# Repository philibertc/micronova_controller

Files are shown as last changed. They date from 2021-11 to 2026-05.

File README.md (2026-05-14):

# micronova_controller  

<a href="https://www.tindie.com/products/philibertc/pellet-heater-controller/">
  I sell on Tindie
</a>
<a href="https://www.paypal.com/donate?hosted_button_id=337V43Y2JEU5L">
  Donate with PayPal
</a>

**Kits are available on Tindie!**  
**_In stock every month._**  

**Here is an overview of the additions:**

- **possibility to reset the settings with a flat screwdriver**
- **IO footprints are now designed to accept screw terminals**
- **D0 and RST are connected for deep sleep**
- **a row of pins has been added to access unused pins**

This Arduino program allows to control easily via MQTT a pellet stove equipped with a Micronova mainboard. Hardware details [here.](https://github.com/philibertc/micronova_controller_pcb/)  
**Discord server: https://github.com/philibertc/micronova_controller/discussions/63**

## License
<br />This work is licensed under a <a rel="license" href="http://creativecommons.org/licenses/by-nc-sa/4.0/">Creative Commons Attribution-NonCommercial-ShareAlike 4.0 International License</a>.
All previous commits [from this one (3 sept 2022)](https://github.com/philibertc/micronova_controller/commit/3b48e56f5a7b02a50885eb272f03c7dd73d8c4e8) are CC-BY-NC-ND and not CC-BY-NC-SA.

## Please check the [Wiki](https://github.com/philibertc/micronova_controller/wiki)

## Thanks
Thanks to [@pedrware](https://github.com/pedrware) for the photo of the mainboard and his explanations of some of the problems encountered.  
Thanks to [ridiculouslab](https://www.ridiculouslab.com/arguments/iot/stufa/micronova_en.php) for his analysis of the serial protocol.  
Thanks to the active Discord community, who keep the project moving.  
Thanks to [PCBWay](https://www.pcbway.com/) for supporting me in the production of PCBs.

## Disclaimer
THIS SOFTWARE IS PROVIDED "AS IS" AND ANY EXPRESSED OR IMPLIED WARRANTIES, INCLUDING, BUT NOT LIMITED TO, THE IMPLIED WARRANTIES OF MERCHANTABILITY AND FITNESS FOR A PARTICULAR PURPOSE ARE DISCLAIMED. IN NO EVENT SHALL THE REGENTS OR CONTRIBUTORS BE LIABLE FOR ANY DIRECT, INDIRECT, INCIDENTAL, SPECIAL, EXEMPLARY, OR CONSEQUENTIAL DAMAGES (INCLUDING, BUT NOT LIMITED TO, PROCUREMENT OF SUBSTITUTE GOODS OR SERVICES; LOSS OF USE, DATA, OR PROFITS; OR BUSINESS INTERRUPTION)
HOWEVER CAUSED AND ON ANY THEORY OF LIABILITY, WHETHER IN CONTRACT, STRICT LIABILITY, OR TORT (INCLUDING NEGLIGENCE OR OTHERWISE) ARISING IN ANY WAY OUT OF THE USE OF THIS SOFTWARE, EVEN IF ADVISED OF THE POSSIBILITY OF SUCH DAMAGE.

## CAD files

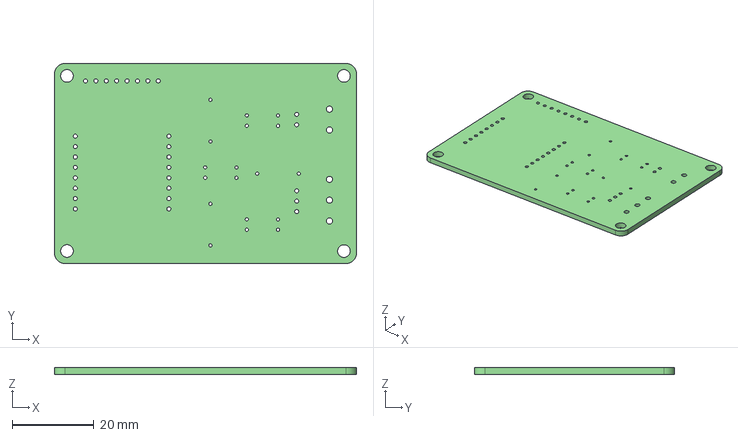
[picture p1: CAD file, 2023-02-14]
Useful things/PCB(v1.2).step
73.8 x 48.9 x 1.60 mm

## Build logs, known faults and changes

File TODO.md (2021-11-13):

### Things to implement in the firmware
- [X] Water pressure read
- [X] Fans speed control (will not be implemented if EEPROM, _not implemented_)
- [ ] Fans speed reading
- [ ] Flame power control (maybe it has to be set in EEPROM, maybe RAM 0x19)
- [ ] Eco off state reading
- [ ] Eco off state writing
- [ ] Eco off timer reading
- [ ] Eco off timer writing
- [ ] Thermostat reading
- [ ] Thermostat writing
- [ ] Ping distance sensor
- [ ] Intake air temp
- [X] Deep Sleep

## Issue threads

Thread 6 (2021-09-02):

Invalid flue gas temperature

philibertc, 2021-09-02:
### Discussed in https://github.com/philibertc/micronova_controller/discussions/5

philibertc, 2021-09-12:
Solved on commit "Fume temp" https://github.com/philibertc/micronova_controller/commit/77ca5469e7868de4700d771c248f1fcc638f5586

philibertc, 2021-10-16:
The problem has been solved for several people, but for some the value is not stored on the same memory address. So I will work on referencing all possible addresses.

philibertc, 2021-11-05:
## List of possible addresses
- 0x3E (default)
- 0x5A

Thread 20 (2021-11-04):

Flue gas temp (was on 0x5A for Micronova Mod0047 EVO) and waterpres incorrect

geraldFS, 2021-11-04:
Hello everyone, today was the day. I used the controls in Homeassistant.

Basically it works - but:
- The smoke temperature does not fit a maximum of 10 ° C
- The water pressure is stated three times too high
- Flame power remains at 0 (but you can only see it in the MQTT Explorer

Pellet stove used:
ITC Layma 18kW
Micronova Mod0047 EVO

Addendum to the interference suppression, as soon as I use the 18V from the motherboard, my WLAN quality drops, now I use an interference suppression board (filtering / smoothing the input voltage), the WLAN reception is good.

philibertc, 2021-11-05:
Hello,
To analyze which addresses might match, you can use this program: [test2bis](https://github.com/philibertc/micronova_controller/blob/master/tests/esp8266/test2bis_read_all_addresses.ino)
Which buck converter do you use? I personally have sufficient smoothing with an LM2596.

geraldFS, 2021-11-05:
Hi there,

these are my standard DC / DC converters, they work wonderfully.
But as I said after I repeatedly had problems with other devices, that they received interference from outside, I got used to always smoothing the voltage with capacitors. Since then, all problems have been resolved.

How do I use the test2bis?

I compiled it and uploaded it but then ...

https://de.aliexpress.com/item/4000259403990.html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

geraldFS, 2021-11-05:
fumesTempAddr = 0x5A

philibertc, 2021-11-05:
> https://de.aliexpress.com/item/4000259403990.html

Ah, okay, these are "mini" models. I'm used to these: https://m.media-amazon.com/images/I/61VvzQgykgL._AC_SY355_.jpg which have a more consistent smoothing.

> I compiled it and uploaded it but then ...

Ah, yes, sorry. You have to open the serial monitor (115200 bauds) to analyze the results and eventually find one corresponding to the value you are looking for.

> fumesTempAddr = 0x5A

It works for you with that value?

geraldFS, 2021-11-05:
```
12:55:41.866 ->
12:55:41.866 -> --------------- CUT HERE FOR EXCEPTION DECODER ---------------
12:55:41.900 ->
12:55:41.900 -> Exception (0):
12:55:41.900 -> epc1=0x43420e04 epc2=0x00000000 epc3=0x00000000 excvaddr=0x00000000 depc=0x00000000
12:55:41.900 ->
12:55:41.900 -> >>>stack>>>
12:55:41.900 ->
12:55:41.900 -> ctx: cont
12:55:41.900 -> sp: 3ffffdc0 end: 3fffffc0 offset: 0190
12:55:41.900 -> 3fffff50:  3ffee080 3ffee650 00000046 3ffee5ec
12:55:41.900 -> 3fffff60:  3fffda00 3ffee650 00000046 402025a4
12:55:41.900 -> 3fffff70:  40202c65 00000046 3ffee5ec 402010e2
12:55:41.900 -> 3fffff80:  3fffdad0 00000000 000000cf 40201160
12:55:41.933 -> 3fffff90:  00000100 00000000 feefeffe feefeffe
12:55:41.933 -> 3fffffa0:  feefeffe feefeffe 3ffee5d8 402026c0
12:55:41.933 -> 3fffffb0:  feefeffe feefeffe 3ffe85d8 401011e1
12:55:41.933 -> <<<stack<<<
12:55:41.933 ->
12:55:41.933 -> --------------- CUT HERE FOR EXCEPTION DECODER ---------------
12:55:41.967 ->
12:55:41.967 ->  ets Jan  8 2013,rst cause:2, boot mode:(3,6)
12:55:41.967 ->
12:55:41.967 -> load 0x4010f000, len 3460, room 16
12:55:41.967 -> tail 4
12:55:41.967 -> chksum 0xcc
12:55:41.967 -> load 0x3fff20b8, len 40, room 4
12:55:41.967 -> tail 4
12:55:41.967 -> chksum 0xc9
12:55:41.967 -> csum 0xc9
12:55:41.967 -> v00043510
12:55:41.967 -> ~ld
12:55:44.111 -> Param=0 value=a90  169
12:56:14.975 ->
12:56:14.975 -> --------------- CUT HERE FOR EXCEPTION DECODER ---------------
12:56:14.975 ->
12:56:14.975 -> Exception (9):
12:56:14.975 -> epc1=0x43420e04 epc2=0x00000000 epc3=0x00000000 excvaddr=0x00000011 depc=0x00000000
12:56:15.008 ->
12:56:15.008 -> >>>stack>>>
12:56:15.008 ->
12:56:15.008 -> ctx: cont
12:56:15.008 -> sp: 3ffffdc0 end: 3fffffc0 offset: 0190
12:56:15.008 -> 3fffff50:  3ffee080 3ffee650 00000046 3ffee5ec
12:56:15.008 -> 3fffff60:  3fffda00 3ffee650 00000046 402025a4
12:56:15.008 -> 3fffff70:  40202c65 00000046 3ffee5ec 402010e2
12:56:15.008 -> 3fffff80:  3fffdad0 00000000 000000cf 40201160
12:56:15.008 -> 3fffff90:  00000100 00000000 feefeffe feefeffe
12:56:15.042 -> 3fffffa0:  feefeffe feefeffe 3ffee5d8 402026c0
12:56:15.042 -> 3fffffb0:  feefeffe feefeffe 3ffe85d8 401011e1
12:56:15.042 -> <<<stack<<<
12:56:15.042 ->
12:56:15.042 -> --------------- CUT HERE FOR EXCEPTION DECODER ---------------
12:56:15.042 ->
12:56:15.042 ->  ets Jan  8 2013,rst cause:2, boot mode:(3,6)
12:56:15.042 ->
12:56:15.042 -> load 0x4010f000, len 3460, room 16
12:56:15.075 -> tail 4
12:56:15.075 -> chksum 0xcc
12:56:15.075 -> load 0x3fff20b8, len 40, room 4
12:56:15.075 -> tail 4
12:56:15.075 -> chksum 0xc9
12:56:15.075 -> csum 0xc9
12:56:15.075 -> v00043510
12:56:15.075 -> ~ld
12:56:17.208 -> Param=0 value=c40  196
12:56:36.567 ->
12:56:36.567 -> --------------- CUT HERE FOR EXCEPTION DECODER ---------------
12:56:36.567 ->
12:56:36.567 -> Exception (9):
12:56:36.567 -> epc1=0x40204f26 epc2=0x00000000 epc3=0x00000000 excvaddr=0x40205236 depc=0x00000000
12:56:36.676 ->
12:56:36.676 -> >>>stack>>>
12:56:36.676 ->
12:56:36.676 -> ctx: cont
12:56:36.676 -> sp: 3ffffdc0 end: 3fffffc0 offset: 0190
12:56:36.676 -> 3fffff50:  3ffee080 3ffee650 00000046 3ffee5ec
12:56:36.676 -> 3fffff60:  3fffda00 3ffee650 00000046 402025a4
12:56:36.676 -> 3fffff70:  40202c65 00000046 3ffee5ec 402010e2
12:56:36.676 -> 3fffff80:  3fffdad0 00000000 00000082 40201160
12:56:36.676 -> 3fffff90:  00000100 00000000 feefeffe feefeffe
12:56:36.676 -> 3fffffa0:  feefeffe feefeffe 3ffee5d8 402026c0
12:56:36.676 -> 3fffffb0:  feefeffe feefeffe 3ffe85d8 401011e1
12:56:36.676 -> <<<stack<<<
12:56:36.676 ->
12:56:36.676 -> --------------- CUT HERE FOR EXCEPTION DECODER ---------------
12:56:36.676 ->
12:56:36.676 ->  ets Jan  8 2013,rst cause:2, boot mode:(3,6)
12:56:36.676 ->
12:56:36.676 -> load 0x4010f000, len 3460, room 16
12:56:36.676 -> tail 4
12:56:36.676 -> chksum 0xcc
12:56:36.676 -> load 0x3fff20b8, len 40, room 4
12:56:36.676 -> tail 4
12:56:36.676 -> chksum 0xc9
12:56:36.676 -> csum 0xc9
12:56:36.676 -> v00043510
12:56:36.676 -> ~ld
12:56:38.814 -> Param=0 value=180  24
12:57:08.924 ->
12:57:08.924 -> --------------- CUT HERE FOR EXCEPTION DECODER ---------------
12:57:09.015 ->
12:57:09.015 -> Exception (3):
12:57:09.015 -> epc1=0x43420e06 epc2=0x00000000 epc3=0x00000000 excvaddr=0x40204f30 depc=0x00000000
12:57:09.015 ->
12:57:09.015 -> >>>stack>>>
12:57:09.015 ->
12:57:09.015 -> ctx: cont
12:57:09.015 -> sp: 3ffffdc0 end: 3fffffc0 offset: 0190
12:57:09.015 -> 3fffff50:  3ffee080 3ffee650 00000046 3ffee5ec
12:57:09.015 -> 3fffff60:  3fffda00 3ffee650 00000046 402025a4
12:57:09.015 -> 3fffff70:  40202c65 00000046 3ffee5ec 402010e2
12:57:09.015 -> 3fffff80:  3fffdad0 00000000 000000ca 40201160
12:57:09.015 -> 3fffff90:  00000100 00000000 feefeffe feefeffe
12:57:09.015 -> 3fffffa0:  feefeffe feefeffe 3ffee5d8 402026c0
12:57:09.015 -> 3fffffb0:  feefeffe feefeffe 3ffe85d8 401011e1
12:57:09.015 -> <<<stack<<<
12:57:09.015 ->
12:57:09.015 -> --------------- CUT HERE FOR EXCEPTION DECODER ---------------
12:57:09.015 ->
12:57:09.015 ->  ets Jan  8 2013,rst cause:2, boot mode:(3,6)
12:57:09.015 ->
12:57:09.015 -> load 0x4010f000, len 3460, room 16
12:57:09.015 -> tail 4
12:57:09.015 -> chksum 0xcc
12:57:09.015 -> load 0x3fff20b8, len 40, room 4
12:57:09.015 -> tail 4
12:57:09.015 -> chksum 0xc9
12:57:09.015 -> csum 0xc9
12:57:09.015 -> v00043510
12:57:09.015 -> ~ld
12:57:11.163 -> Param=0 value=160  22
12:57:41.301 ->
12:57:41.301 -> --------------- CUT HERE FOR EXCEPTION DECODER ---------------
12:57:41.301 ->
12:57:41.301 -> Exception (0):
12:57:41.301 -> epc1=0x43420e04 epc2=0x00000000 epc3=0x00000000 excvaddr=0x40204f30 depc=0x00000000
12:57:41.301 ->
12:57:41.301 -> >>>stack>>>
12:57:41.301 ->
12:57:41.301 -> ctx: cont
12:57:41.301 -> sp: 3ffffdc0 end: 3fffffc0 offset: 0190
12:57:41.301 -> 3fffff50:  3ffee080 3ffee650 00000046 3ffee5ec
12:57:41.301 -> 3fffff60:  3fffda00 3ffee650 00000046 402025a4
12:57:41.382 -> 3fffff70:  40202c65 00000046 3ffee5ec 402010e2
12:57:41.382 -> 3fffff80:  3fffdad0 00000000 000000ca 40201160
12:57:41.382 -> 3fffff90:  00000100 00000000 feefeffe feefeffe
12:57:41.382 -> 3fffffa0:  feefeffe feefeffe 3ffee5d8 402026c0
12:57:41.382 -> 3fffffb0:  feefeffe feefeffe 3ffe85d8 401011e1
12:57:41.382 -> <<<stack<<<
12:57:41.382 ->
12:57:41.382 -> --------------- CUT HERE FOR EXCEPTION DECODER ---------------
12:57:41.382 ->
12:57:41.382 ->  ets Jan  8 2013,rst cause:2, boot mode:(3,6)
12:57:41.382 ->
12:57:41.382 -> load 0x4010f000, len 3460, room 16
12:57:41.382 -> tail 4
12:57:41.382 -> chksum 0xcc
12:57:41.382 -> load 0x3fff20b8, len 40, room 4
12:57:41.382 -> tail 4
12:57:41.382 -> chksum 0xc9
12:57:41.382 -> csum 0xc9
12:57:41.382 -> v00043510
12:57:41.382 -> ~ld
12:57:43.537 -> Param=0 value=140  20
12:58:02.891 ->
12:58:02.891 -> --------------- CUT HERE FOR EXCEPTION DECODER ---------------
12:58:02.891 ->
12:58:02.891 -> Exception (9):
12:58:02.891 -> epc1=0x40204f26 epc2=0x00000000 epc3=0x00000000 excvaddr=0x40205236 depc=0x00000000
12:58:02.891 ->
12:58:02.891 -> >>>stack>>>
12:58:02.891 ->
12:58:02.891 -> ctx: cont
12:58:02.891 -> sp: 3ffffdc0 end: 3fffffc0 offset: 0190
12:58:02.891 -> 3fffff50:  3ffee080 3ffee650 00000046 3ffee5ec
12:58:02.891 -> 3fffff60:  3fffda00 3ffee650 00000046 402025a4
12:58:02.973 -> 3fffff70:  40202c65 00000046 3ffee5ec 402010e2
12:58:02.973 -> 3fffff80:  3fffdad0 00000000 00000082 40201160
12:58:02.973 -> 3fffff90:  00000100 00000000 feefeffe feefeffe
12:58:02.973 -> 3fffffa0:  feefeffe feefeffe 3ffee5d8 402026c0
12:58:02.973 -> 3fffffb0:  feefeffe feefeffe 3ffe85d8 401011e1
12:58:02.973 -> <<<stack<<<
12:58:02.973 ->
12:58:02.973 -> --------------- CUT HERE FOR EXCEPTION DECODER ---------------
12:58:02.973 ->
12:58:02.973 ->  ets Jan  8 2013,rst cause:2, boot mode:(3,6)
12:58:02.973 ->
12:58:02.973 -> load 0x4010f000, len 3460, room 16
12:58:02.973 -> tail 4
12:58:02.973 -> chksum 0xcc
12:58:02.973 -> load 0x3fff20b8, len 40, room 4
12:58:02.973 -> tail 4
12:58:02.973 -> chksum 0xc9
12:58:02.973 -> csum 0xc9
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
geraldFS, 2021-11-05:
fumesTempAddr = 0x5A

It works for you with that value?

Yes!

philibertc, 2021-11-05:
Cool! One problem solved quickly
For the water pressure, if it is constantly 3× higher you can edit the [line 369](https://github.com/philibertc/micronova_controller/blob/ee899ee48db1be8ea5414a327f024a538e55d4d3/micronova_controller.ino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) by adding ` / 3`.

geraldFS, 2021-11-05:
I've already thought about this, but that shouldn't be the solution.

I am afraid I am using the wrong value or my oven is not delivering it.
I have to deactivate the water pressure measurement during the initial setup as soon as the pipeline set is installed.
Therefore I fear that the value in the form no longer exists.

Italian technology that inspires ;-))

But I can live very well without the water pressure, there are other things that press me more.

philibertc, 2021-11-05:
> I've already thought about this, but that shouldn't be the solution.

Yes, but only until then. There's still the flame power reading to fix, right?

geraldFS, 2021-11-05:
With the new .ino of today, errors are gone, now the heating power requirement goes.

the value that is displayed for water pressure also corresponds to what has been transferred, think either the oven delivers a fake value.

I just drained the water because I installed a small return increase and the value stayed exactly the same ...

geraldFS, 2021-11-15:
Hi there,

I can confirm that the ITC Layma (18Kw) works with the Micronova Mod 0047 EVO.

There are two changes to the standard version:
- fumesTempAddr = 0x5A
- water pressure is not used by the control; it must always be deactivated. (see manual)

But otherwise TOP!

philibertc, 2021-11-15:
Hello,
thanks for the contribution!

Closed 2021-11-05.

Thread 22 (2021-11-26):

Problems with power OFF / power demand

geraldFS, 2021-11-26:
Hi there,

QA strikes again ;-)

Since the penultimate change to the source code, I have had the symptoms that I cannot switch off the oven if it has been running for a long time.
I can shift gears, but it continues to burn stubbornly.

The water temperature and room temperature are updated and are valid.
Only the switch on / off and the power requirement are frozen.

When I switch off the oven on the display, everything is updated and works again.

Regards
Gerald

philibertc, 2021-11-26:
Hello, I will roll back to the previous commit, that new changes were
untested but I forgot to switch on dev branch.

Le ven. 26 nov. 2021 à 12:05, Gerald ***@***.***> a écrit :

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

philibertc, 2021-11-26:
I revert the changes

geraldFS, 2021-11-26:
Thanks!
Reacts again :-)

geraldFS, 2021-12-07:
Hi there,

with the version dated December 4th, 2021 - the same phenomenon occurs again!

Switching on is possible
Switching off is not possible

Values are all displayed accordingly.

philibertc, 2021-12-07:
Hello, that's strange...
I will inspect this soon.

philibertc, 2021-12-07:
Hello, I reread the code, but I do not see anything that could influence the extinction. I will have to do some investigation.

philibertc, 2021-12-12:
Hello, until I have more information about this problem, I will roll back to the previous functional version.

philibertc, 2022-02-27:
Hello,
I'm going to make some simplifications in the program this weekend (especially in the web settings that I'm going to minimize to the wifi configuration until I know how to manage the rest better). This should make it easier to diagnose bugs like this one!

Best Regards,
Philibert

philibertc, 2022-09-11:
Hello,
Can I close this issue?

Sincerely,
Philibert

geraldFS, 2022-09-20:
Yes!

Closed 2022-09-20.

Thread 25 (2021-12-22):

make it works with ESPHOME

raziel83257, 2021-12-22:
It would be wonderfull to make it works with ESPHOME, that is also integrated with HomeAssistant:
https://esphome.io/index.html

philibertc, 2021-12-22:
Hello, I was thinking something more like this: https://github.com/philibertc/micronova_controller/discussions/15
For now I will make some other small improvements.
One day I'll probably make an esphome version.

Sincerely,
philibertc

geraldFS, 2022-09-20:
Perfect!
ESPhome would be the gold edge solution ;-)

Gerald

vyruz1986, 2022-11-10:
[This project](https://github.com/edenhaus/esphome-extraflame) offers a ESPHome component, pretty should it should work with the hardware of this project, as both software solutions (the arduino file in this repo, and the ESPHome config of the other repo) configure RX/TX pins which go to the stove's data pin

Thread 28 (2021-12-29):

Parameter based on model/type?

liquidacid, 2021-12-29:
Hi,

Currently im using your tool to fill my Home Assistant. It seems there is not really a good database of addresses available. I have an Artel Hydro stove and would like to share my address list based on the board in it. Maybe it would be awesome to build up a database of addresses?

Im about to adding more stuff which is interesting like fan speed, settings like amount of added pallets per time slot etc so you can combined with water temperature see if your stove needs to be cleaned over time etc.

philibertc, 2021-12-29:
Hello
>It seems there is not really a good database of addresses available

Yes, I'm building it with time, I'll soon create a document summarizing various things about the protocol used and the addresses.

>Im about to adding more stuff which is interesting like fan speed, settings like amount of added pallets per time slot

Unfortunately these parameters have to be written to the EEPROM, which is a memory that wears out rather quickly (about 10000 writes) and I haven't yet found a safe way to limit the number of writes in case of a bug.

Sincerely, philibertc

liquidacid, 2021-12-29:
I do understand, i don't want to write the values but only read them to make sure what the current settings are. They only should be sent once to the MQTT topic once they are changed in the stove i think so you can perfectly see the details.

I also got a very different set of addresses.

I suggest to make some different species in a seperate file where you can choose from to select the right stove?

philibertc, 2021-12-29:
> but only read them

Okay, in this case it's easy, I just didn't take the time to test the EEPROM reading, but it won't take me long to set up.

> I suggest to make some different species in a seperate file where you can choose from to select the right stove?

Yeah, that's a good idea, I will do that quickly.

liquidacid, 2021-12-29:
Im not asking you to do this, i can help if you like but if i only make it for myself its probably not the cleanest way of coding it.

philibertc, 2022-01-02:
Hello
Don't worry, I have to do it. If you want to make tests you can try to modify the program: https://github.com/philibertc/micronova_controller/blob/master/tests/esp8266/test2_read.ino
Sincerely, philibertc

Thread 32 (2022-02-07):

problem with micronova card of the year 2010

riccmike, 2022-02-07:
Thanks for your work, I tried to apply it to my Pellets Ecoteck stove with micronova board of the year 2010. With your code I didn't have any messages in the Serial Monitor, so I modified the code to understand what happens. I found that in my case, in the checkStoveReply function the rxCount variable is always zero. How has this ever happened to you? Perhaps the firmware of my board does not support communication, even if the serial connector is present.
I thank you in advance.

philibertc, 2022-02-12:
Hello, if there is the connector it is almost sure that it can communicate, because it can be useful in some cases for the repairer in case of failure.
This may be due to a bad connection. You can try this program to see if the stove reacts: https://github.com/philibertc/micronova_controller/blob/master/tests/esp8266/test1_on_off.ino
This program simply turns the stove on and off two seconds later.

Sorry for my late reply,
Sincerely,
philibertc

philibertc, 2022-02-16:
Hello,
This is really embarrassing.
Are you sure you have connected the cables correctly?
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
Sincerely,
philibertc

riccmike, 2022-02-16:
next weekend, I take the stove out of its position and retest the connector. Let's hope for my mistake. I will keep you updated.

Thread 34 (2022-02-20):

Add compatibility for ESP-01 and Breakout board

wes1993, 2022-02-20:
Hello,
could you help me to add compatibility for this board?
https://it.aliexpress.com/item/1005001970616935.html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

The breakout board can convert from 5V to 3.3V and also adapt the signal but need TX and RX pin, in this board we have only one serial PIN so i don't know how can i adapt this...

Best Regards
Stefano

philibertc, 2022-02-21:
Hello,

It will not be possible to adapt this breakout board because it is not advanced enough, it would need a few more GPIOs.
However, it should be possible to adapt the program for the ESP-01, still using the circuit with the optocouplers, but sacrificing some features like the serial port, which is very useful if everything does not work as expected.

Best Regards,
Philibert

wes1993, 2022-02-21:
Thanks a lor Philibert for your fast reply :-D
So i think i will keep the ESP8266 i just need to know what are the optocouplers to buy, do you have some link?
And did you know name/model of the female connector of the serial port on the micronova side?

Thanks a lot
Stefano

philibertc, 2022-02-21:
The optocouplers are PC817, 3 are needed
The esp8266 that fits best is the wemos d1 mini, which you can find by searching "d1 mini" on AliExpress or Amazon.
For the cable, this should be adequate: https://it.aliexpress.com/item/1005003638697583.html with 4 pins, 50cm mini and a female connector on one side.

Best Regards,
Philibert

wes1993, 2022-02-21:
Thanks again for your fast reply!!! :-D
I have found one Wemos D1 mini :-D so perfect i have the esp8266 i kust need the PC817... I have found two type of PC817 could you help me plese?:
This:
https://it.aliexpress.com/item/32719957788.html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

or this:

https://www.ebay.it/itm/173890434826?itemid=173890434826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

Best Regards
Stefano

philibertc, 2022-02-21:
The second one will be perfect!

wes1993, 2022-02-21:
Perfect thanks a lot!! :)
I’ll keep you updated and If I have some time I want to port this project on Blynk so we have an App and also HA integration

wes1993, 2022-02-22:
Hello Again @philibertc,
I have created the circuit and everything works fine!!!
I have only one question, there is a way to power on the ESP via 5V on the motherboard?

Best Regards
Stefano

philibertc, 2022-02-22:
Hello,
Glad everything is working!
I don't know if the stove is able to provide enough power via the 5V line, so I recommend using the 20V line with a converter like an LM2596 to get that down to 3.3V.

Best Regards,
Philibert

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

philibertc, 2022-02-22:
By the way, what is the model of your stove? So I can add it to the list of known models.

wes1993, 2022-02-22:
My stove is an El.Fire Venice Slim :)
But I should connect the GND together with the GND of ESP so did you think i could do that?

+ 20 V —> Converter —> Vin5V
GND    —> Converter —> GND of ESP

is the scheme correct?

wes1993, 2022-02-22:
P.S. I’m also trying to implement OTA updates, I will keep you update :)

Best Regard
Stefano

philibertc, 2022-02-22:
20 V —> Converter —> Vin5V *or 3V3 depending on the converter setting* but it is basically the same thing
GND —> Converter —> GND of ESP *= GND → Converter and GND → GND of ESP*

> My stove is an El.Fire Venice Slim :)

Thanks!
> I’m also trying to implement OTA updates, I will keep you update :)

That would be great, thank you very much!

wes1993, 2022-02-22:
Perfect thanks a lot :)

wes1993, 2022-02-22:
Hey another question.. sorry for the disturb :(
Did you know if there is a way to set the temperature and the clock?

philibertc, 2022-02-23:
Hello,
We are currently discussing it here: https://github.com/philibertc/micronova_controller/discussions/30 but for the moment the most reliable solution is to emulate the IR remote control.

Best Regards,
Philibert

wes1993, 2022-02-23:
ok perfect thanks a lot

wes1993, 2022-02-27:
Hello Philibert,
I have a question, I really really don’t understand why we need the 500 ohm resistor… could you help me?

Because I want, i case something won’t work, to attach the Micronova board to an arduino to convert TTL
To usb, but I think arduino is 5 v so I need to know if I just need to power the optocoupler via arduino and I have 5V or I also need to remove the resistor.

thanks a lot
Stefano

philibertc, 2022-02-27:
Hello,
an optocoupler works like this:
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
When we turn on the LED (on the left) the phototransistor on the other side becomes conductive. The 500 Ohms resistor (470 on the diagram) just allows not to burn out the led.

Electronically speaking, replacing the ESP by the Arduino works: the 500 Ohm resistor is also sufficient for 5V and not only 3V3. However, the Micronova board uses a strange serial configuration which is not available in the SoftwareSerial library for Arduino:
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
I will send you the procedure to use the Arduino as a serial converter, without using any program on it (just connecting to the RX and TX pins) and using a software like [YAT](https://sourceforge.net/projects/y-a-terminal/).

Best Regards,
Philibert

PS: I closed the issue but we can still discuss here.

wes1993, 2022-02-27:
@philibertc thanks a lot for your reply!! :) I will wait your instructions!! :)

philibertc, 2022-02-27:
I forgot a detail, in fact I realize that it is not possible to use to Arduino, even using it as a FTDI for example. The only solution is to use a program for the esp, which would play the role of a kind of bridge between the computer and the micronova board. I'm looking into how to do that.

wes1993, 2022-02-27:
Ok perfect thanks a lot!’ I will wait!’ :)

wes1993, 2022-02-28:
This is a WP of the mobile App:

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

what do you think? Do you like this?

bernardstef, 2022-02-28:
Hi !
I've been following this project and using it for a while ! Awesome to see a mobile app, I have the micronova wifi module (easy connect plus) + play store app and it's not the most reliable ..

wes1993, 2022-02-28:
I’m working on this, for now seems very powerful I just need to know how can we write value to eeprom in a safe way, I need the help of @philibertc for this and we could have the exact same function of the stock App.
This could be used for example for set the timer

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

best regards
Stefano

wes1993, 2022-03-01:
Hello,
I have some news :-D I have seen that someone has added the OTA code i will share my Blynk code also and i have added also the DUMP memory via a simple terminal command without connecting the device to PC.

@philibertc could you tell me if the values of params are decimals or HEX values?

Because for now i need to write the value in decimal otherwise the terminal can't accept the value.

Best regards
Stefano

wes1993, 2022-03-01:
Added also some Graph
![Uploading AD0D90D0-D85B-4F34-A5B0-ED079E0FAE80.png…]()

philibertc, 2023-02-10:
Hello,
I'm reopening this issue as I seem to have missed a lot of the discussion, sorry for that.
Has there been any progress?

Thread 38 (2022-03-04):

Why a 500 Ohm resistor

netdata-be, 2022-03-04:
Hi there,

I'm developing my own PCB because and I'm using your project as a base, thanks for that !

I'm just wondering why you picked a 500 ohm resistor, let me try to explain:

- 5V / 510 Ohm =  0,0098 A  == 9,8 mA
- 3,3V / 510 Ohm =  0,00064 == 6,4 mA

Since an optocoupler is just a LED it is designed to have 20mA over the IR LED

This means the ideal resistor should be:

- 5V / 0,02 A = 250 Ohm
- 3,3 V / 0,02 A =  165 Ohm

I'm guessing the led emits enough IR to activate the collector and thus work.
Or I'm I missing something?

philibertc, 2022-03-04:
Hello,

You are right, 250 Ohms resistors would be enough for that, but using about 500 allows to have a margin, because of the variable quality on sites like AliExpress but also to draw as little as possible on the 5V supplied by the stove.

Best Regards,
Philibert

PS: I'm closing this issue but you can still comment
https://github.com/philibertc/micronova_controller/issues/34#issuecomment-1053326781

Closed 2022-03-04.

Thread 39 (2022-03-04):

Why the use of the enable RX

netdata-be, 2022-03-04:
I'm wondering why you choose to use a GPIO to enable the RX from the 1wire RS232?
I would be interested to know the reason behind this.

philibertc, 2022-03-04:
Hello,
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
If you don't use the "enable RX" the RX optocoupler (in the middle) will act as a pullup as soon as you try to use the TX (at the bottom) : when the TX pin is set to GND, the current can pass from the other side (from pin 4 to 3) to GND and in the process allow the current to pass through the optocoupler in the middle, which will act as a pullup. The Stove_Serial pin therefore never makes the low signal.
This is one of the problems of half-duplex serial (on a single cable).
I hope my explanation is clear,

Best Regards,
Philibert

Closed 2022-03-06.

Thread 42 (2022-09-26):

Extraflame luisella stove not working/responding, other 4-pin pinout?

jeanpolle, 2022-09-26:
Hi everyone!

I have a luisella (extraflame) stove with 4-pin connector on on the back, but i can't get it working with the esp...
Before i take the stove off the pipe to have a look at the card internally; i thought i'd ask here; maybe i'm missing something obvious, i'm rather new to arduino ;)

i got the PCB from tindie, and have an ESP8266 wemos D1 mini fitted. Soldering all components went smooth. don't think i made an error there. (pics attached)

Programming the ESP doesn't work when it is fitted tot the PCB board however... it has trouble connecting, and the led starts blinkin erratically.
Once I remove it from the pcb, uploading the code works just fine. Can anyone comfirm the same behaviour?
i use the micro usb port to power the ESP.

Wifi setup works fine, I have a broker set up (mosquitto in a docker container) and can see the "pong" appear nicely every 25s.

I checked the serial port on the stove before connecting (good thing i did ;)), and when measuring the voltages i noticed a difference in pinout,  I found it to be: (gnd - 5v - 20v - ser) instead of  the documented (gnd - ser - 20v - 5v)

I hooked up the board, but nothing comes up other than the pong

-I tried the 2sec on/off program, but no reaction from the stove
-Test read.ino with a serial monitor running doens't show anything messages.

anything else you can think of? anyone found serial messages to be turned off in some admin menu-thing on the stove itself?

thanks!

J

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

philibertc, 2022-09-26:
Hello!
First of all, thank you for detailing your issue.
> don't think i made an error there.

Yes, it looks all good.
> Once I remove it from the pcb, uploading the code works just fine. Can anyone comfirm the same behaviour?

I have the same behavior, it's because of the link between D0 and RST which is used to add the possibility of deep sleep.
> i noticed a difference in pinout, I found it to be: (gnd - 5v - 20v - ser)

The serial and 5V pin are both at 5V, how did you tell the difference?

I hope I have answered a majority of your questions!
Do you have some resistors (above 1kOhm) and a multimeter at your disposal? There is a way to surely differentiate between serial and 5V.

Have a great day,
Philibert

jeanpolle, 2022-09-26:
Hi Philibert,

First of all, thanks for the excellent work done so far, great stuff! quite stunned :)

> The serial and 5V pin are both at 5V, how did you tell the difference?

Well..I wasn't sure what voltage to expect on the serial pin when measuring.
I have a pin which caries no voltage referenced to ground, and since I already had a 5v and 20v present; i figured it was the serial pin .. (was gonna ask how to be sure of this ;))

So that would explain why i get nothing; the 5v pin i measure will be the serial as per original pinout...
I do have resistors/multimeter at my disposal so if you got a trick to make sure, i'm all ears

Now what to do with the pin with no voltage... i measured it a few time, and to the ground pin i have 0v where you have 5v :)

i'll hook the pinout up as per spec/doc tonight or tomorow

Thanks for the help!

J

philibertc, 2022-09-26:
> I do have resistors/multimeter at my disposal so if you got a trick to make sure

Okay, nice!
To check which pin is serial, put your multimeter between GND and one of the two 5V pins. After, connect this pin to the GND via a resistor of more than 150 Ohm (not to make a short circuit or exceed the limit of 0.25W of a resistor), you can check if this pin is now at 0V. In this case, it is the serial pin, otherwise, it is the power supply pin.
Is this clear? I could make a diagram if you want.

From what you have described, the pinout described on the doc should actually be good, but it is always good to check.

Regards,
Philibert

jeanpolle, 2022-09-28:
Hi Philibert

little time, little knowledge, so progress is slow :)

I measured all pins again, and tried the resistor test to pull the serial to 0V.
It identified the documented 5V pin as the serial, good news!
The other pin (power) however remains at 0v instead of 5V all the time.

nevertheless, I corrected the wiring to the PCB and hooked it up to the stove but got no other messages from the ESP on the subscribed broker channels than "connected" on /pong.

nothing on /ambtemp, /state or /onoff

I connected another mqtt client to the broker and published messages on these topics, to check if my broker setup was working correctly. They showed up just fine on the first client.

I can however turn on the stove by publishing ON to /intopic, but the stove wont turn off when sending OFF.

I then loaded the on/off test.ino, and that worked. The stove went on and off again. Nice!
So why wont it turn OFF then when publishing OFF to /intopic.... weird.

it looks like a problem in this earlier thread...
https://github.com/philibertc/micronova_controller/issues/31

any ideas?

thanks!

J

philibertc, 2022-10-05:
Hello, first of all, sorry for my late reply
> So why wont it turn OFF then when publishing OFF to /intopic.... weird.

It is indeed strange. The fact that the ON/OFF test works already lets us know that it is not an address problem. When you send the message to turn off, does the blue LED of the WeMos blink (once and then several times right after)?

> it looks like a problem in this earlier thread...
https://github.com/philibertc/micronova_controller/issues/31

The problem does seem to be the same. I'll try to build a more advanced test program to find out what's wrong. The OFF command is normally built the same way as the ON, if one works I wonder what is blocking the other.

Bests,
Philibert

jeanpolle, 2022-10-06:
> Hello, first of all, sorry for my late reply

No problem, enough work to do here :)

> It is indeed strange. The fact that the ON/OFF test works already lets us know that it is not an address problem. When you send the message to turn off, does the blue LED of the WeMos blink (once and then several times right after)?

I remember the led blinking once when sending ON, and not blinking when sending OFF.
i'll try to confirm this later tonight.

> I'll try to build a more advanced test program to find out what's wrong. The OFF command is normally built the same way as the ON, if one works I wonder what is blocking the other.

the fact that no other parameters are published on any of the other topics (ambtemp / status / ...), would that solely be due to different addresses?

Thanks!

J

jeanpolle, 2022-10-25:
Hi guys,

got a bit of time on my hands; can anyone point me in a direction of things i can try?
Verify my method on how to run a serial monitor?
(running one in arduino IDE with the ESP connected via microUSB, and the serial connections to the stove, but i get absolutely nothing :))

J

philibertc, 2022-10-27:
> EDIT:
> The led blinks 1x short + 4x short when sending ON
> The led blinks 4x short when sending OFF

Hello!
All is good for the ON command, but it seems that the OFF command is not sent because the LED does not flash once in the first place.

Can you try reversing the ON and OFF command to see if the stove turns off (sending "on", since it will be reversed).

Bests,
Philibert

jeanpolle, 2022-10-27:
Hi Philibert,

Can you be more specific on how i should reverse the commands?

Would this mean altering the INO file and reuploading it to the ESP?
(as in; would reversing values in line 43 and 44 suffice? i'm a total noob at this)

Or am i missing an easier way?

kind regards!

J

philibertc, 2022-10-27:
that modification bypasses the two if conditions using ```if (true)```

jeanpolle, 2022-10-27:
Thanks so much; that works!

So the trouble lies in the controller reading the stove's status to be able to fullfill the condition, and only then send the command.

I don't get any data on other topics, so that problem is related....

What are the next steps to determine what goes wrong? other addresses, and how to find them?

Thanks for taking the time to help me out here; i'm learning a bunch of stuff ;)

Jan

msaitz, 2022-11-22:
I'm having the same issue with a Laminox Idro marichiara, I can only turn it ON with no additional actions or readings from the stove.
I'll be doing some additional testing to see if my issue fully matches @jeanpolle

jeanpolle, 2022-12-17:
did anyone make any progress?

@msaitz did you manage to get readouts?

msaitz, 2022-12-23:
@jeanpolle I haven't had time for it yet!

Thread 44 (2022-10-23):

MCZ Ego

ThomasTom86, 2022-10-23:
Good morning,
 I came across your amount when I was looking to make my pellet stove smart.  Unfortunately, my oven (MCZ Ego Air 2017) does not have a CN 13 port installed.  Is it still somehow possible to integrate this model into the iobroker via mqtt?  There is an original Wifi module for this oven (unfortunately very expensive).  Thanks

https://youtu.be/yPMMZ5ETMB8

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

jeanpolle, 2022-10-25:
If i had to guess; i'd say the 4 pins marked "com" are candidate for serial communication....

philibertc, 2022-10-27:
Hello,
According to the video, the "COM" pins seem to match. The use of only three cables also seems to confirm that it is the same protocol. You can make measurements with your multimeter by connecting the GND of the voltmeter to the 2nd from the left, then measuring the rest of the pins with the red probe.

Best Regards,
Philibert

ThomasTom86, 2022-10-27:
Thank you for your message.  This is the measurement result from the Com port.

Best regards
Tom
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

ThomasTom86, 2022-10-28:
I still found that
![Uploading E82E7FE0-994B-4061-98B0-E1E368BE3538.jpeg…]()

ThomasTom86, 2022-10-28:
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

Closed 2023-09-10.

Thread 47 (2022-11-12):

Wiring for La Nordica Extraflame Emma Plus

vyruz1986, 2022-11-12:
Hi,

First of all, thanks for putting this project together!

I'm trying to use this project to control/monitor the aforementioned pellet stove, but am struggling to find the right connections.
The control board I have is the one listed in [this PDF](https://www.extraflame.it/support/index.php?option=com_docman&Itemid=26&task=doc_download&gid=916) on page 40, 'board code' (whatever that may mean) 00227575.
Here's a picture of the board (sorry for poor quality, I took it from a webshop since mine is in the stove and I don't want to spend time disassembling it):
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

As you can see the 'Seriale' connector is positioned otherwise than in the readme of this repository.
In my stove, there is also a cable connected to it (tested all 3 wires, it's just an extension cable), which has a panel mount connector (exactly the same type as on the board) on the rear of the stove:
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

I also noticed that the extension cable only has 3 wires, while the board connector has 4 pins.
I measured all 4 pins with my DMM, and got the following results (numbering following your drawing of the connector in the readme):
1. GND, blue wire in extension cord (confirmed by measuring continuity between this pin and the negative CMOS battery pin
2. Black wire in extension cord, measuring constant +5V
3. Red wire in extension cord, measuring fluctuating +17-19V (approx every second)
4. No wire in extnesion cord, measuing constant +5V

I also measured all pins with my oscilloscope, but no obvious digital signal is visible.

So I'm at a loss as to which pin is the serial data pin, can someone help me out?

jeanpolle, 2022-11-16:
Hi!

looks like you are as confused as i was/am.... and are possibly running into the same problems. :)

have a look here;

https://github.com/philibertc/micronova_controller/issues/42#issue-1385697452

i found i can send stuff to the stove on the pinout philibert descibes (i assume yours will be the same) but cannot get a readout from the stove so we had to adapt the ino a bit to get the messages sent.

haven't scoped the output of my stove yet..

J

vyruz1986, 2022-11-16:
I forgot to mention I was (beside this and [this](https://github.com/netdata-be/PalletHeater-REST-API/issues/1) repository) also looking into [this](https://github.com/edenhaus/esphome-extraflame) solution, which I found the most attractive since it uses ESPHome allowing me to easily modify and upload new firmware in the future. With some help from @edenhaus I was able to get it working yesterday. The serial pin was indeed the 5V pin (pin #2) which was brought to the backpanel connector via the black wire.
I used this schematic to hook up my ESP8266:
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

It's different from the one described here , which I believe is better (since it uses optocouplers and offers complete isolation of ESP and stove), but as discussed above I couldn't get this schematic working :(
Also note that @edenhaus's solution doesn't require the `Enable_RX` pin which this solution needs.

edenhaus, 2022-11-17:
@vyruz1986 I have a logic shifter between the esp and the oven as the esp is not 5v tolerant.
I used a chinese copy of https://www.sparkfun.com/products/12009

vyruz1986, 2022-11-17:
> @vyruz1986 I have a logic shifter between the esp and the oven as the esp is not 5v tolerant. I used a chinese copy of https://www.sparkfun.com/products/12009

I know but I didn't have any logic shifter available, so I started with ESP8266 which is 5V tolerant (although not officially, I've used this MCU with 5V logic many times without problems. Also see [this](https://hackaday.com/2016/07/28/ask-hackaday-is-the-esp8266-5v-tolerant/)).
I have ordered logic shifters and will switch to ESP32 as soon as they arrive.

edenhaus, 2022-11-17:
Nice to know about the 5v tolerant. Maybe I will change on my load weight cell project to 5V to have a better precision. Thanks :)

@vyruz1986 It would be great to add the schematic above with the logic shifter to my repo. As you have already drawn it, feel free to add it with a PR :)

philibertc, 2022-11-17:
Hello,
> I also measured all pins with my oscilloscope, but no obvious digital signal is visible

This is normal: the stove does not send any information until it is asked.

> So I'm at a loss as to which pin is the serial data pin

According to this diagram it must be the second pin "Black wire in extension cord, measuring constant +5V" you measured:
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
the position of the "seriale" connector varies between the different models of micronova cards.

Best Regards,
philibertc

philibertc, 2022-11-17:
Have you tried any of the test programs?

bachtsevanis, 2023-02-20:
@vyruz1986 can you explaine how you connected with the board? I don't know how to read the diagram that you upload. My stove board has the same serial as yours. It's a Micronova J034_7

vyruz1986, 2023-02-21:
> @vyruz1986 can you explain how you connected with the board? I don't know how to read the diagram that you uploaded. My stove board has the same serial as yours. It's a Micronova J034_7

Read [this chapter](https://github.com/edenhaus/esphome-extraflame/blob/main/docs/connection.md#finding-the-right-pins) to find out how to identity the pins on your stove connector.
Once you found GND and DATA, connect GND to the ESP, and use a 1N4148 diode to wire the stove's DATA pin to the ESP's RX pin, with the black mark on the diode facing the ESP. Then branch another wire from the stove's DATA pin and connect it to the EPS's TX  pin.

bachtsevanis, 2023-02-22:
@vyruz1986 I suppose that you are not using external power ie USB power adapter like this solution?

rotragit, 2023-10-28:
Extraflame doen't wire the 5V pin on the backside socket. But you can get it from the socket on the controller. Use that one.

pippo93, 2024-11-10:
Any update about this issue? I have now finished the assembly of pcb as showed in this repo but I have the same Micronova Controller of the firat comment…

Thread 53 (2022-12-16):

Question about 5V Pin

eni23, 2022-12-16:
Hey @philibertc

I have a pellet stove (L'Asolana Marina) which clearly has a Micronova controller board, but i'm unable to access the PCB for interfacing with it. But it has a SUB9 connector on the back with has 3 connected pins (GND,20V,Serial).

 I would like your circuit, but the optocoupler that is connected to `RX_ENABLE` needs 5V which i do not have with the 3P-connection. Since its only driving a  optocoupler, i was thinking about using a step-down board and use the 20V to drive this optocoupler. Do you think this will work or is it too dangerous to try it? Any ideas?

I would use a circuit like this:
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

The official micronova WIFI board [pcb front](https://www.micronovasrl.com/wp-content/uploads/2016/02/DSC_2024.jpg) [pcb back](https://www.micronovasrl.com/wp-content/uploads/2016/02/DSC_2020.jpg) also only connects 3 pins and seem to directly convert the 20V down as well.

Thanks in advance :)

philibertc, 2022-12-26:
Hello!
Using a buck converter to do this is not a problem, you can definitely use this method.

Have a great day,
Philibert

eni23, 2022-12-27:
Thanks a lot for your answer. I tried it today and the stove replied and turned on as excepted. I will close here but will create a MR in the next few days to add my model to the supported ones in README.md.

Have a nice day as well :)

Closed 2022-12-27.

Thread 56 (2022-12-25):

Use the 5V from the new micro serial output.

maxcalavera81, 2022-12-25:
Hello @philibertc, what is the inconvenience of using the 5V output of the micro nova board to power your pcb and the wemos d1 mini?  So it would be possible to power everything without the need for external power.  I look forward to feedback, thank you very much for your attention...

philibertc, 2022-12-26:
Hello, the problem is that I don't know the maximum power available on this 5V line, while the ~20V line is the main low voltage supply of the stove, so I prefer to use this one through a buck converter.
So this is just a precaution.

Best Regards,
Philibert

Closed 2023-01-22.

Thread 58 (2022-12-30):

Safer way to turn the stove off

eni23, 2022-12-30:
Turning the stove on works fine over writing `0x01` to `RAM 0x21`, turning it off (sending `0x06` to `RAM 0x21`) seems to be problematic. My stove enters "turning off mode" but takes pretty long to do so (~50min), so this is not the procedure used by programs or the power button which takes around 10min. Searching around in the internet told me that i am not the only one which has this issue. The stove also has a infrared control, which seem to write commands to `RAM 0x58`. So sending 10 times `0x5a` to `RAM 0x58` with a delay of `100ms` turns the stove off safely.

You should consider changing your code to this method as well, since it seems the better way and also should work for all stoves.

There are other "IR commands" that can be written to `0x58` with a delay of `100ms`. To set power and temp, send it at least twice, for the power button (longpress) at least 10 times.

| State | Description   |
|-------|---------------|
| 0x54  | Power +       |
| 0x50  | Power -,      |
| 0x52  | Temperature + |
| 0x58  | Temperature - |
| 0x5a  | Power ON/OFF  |

philibertc, 2023-01-22:
Hello,
Thank you for your contribution!
I'm testing this out as soon as I can, then I'll probably incorporate it.
Bests,
philibertc

maxcalavera81, 2023-01-29:
I think I have the same problem. Because whenever I turn off the stove, I can turn it back on again. I don't really know what's going on.

paciotti, 2023-12-31:
Hello
I want to try this method for turning the stove ON and OFF since the original one is not working for my hydro stove.
How should we manage the checksum? If I'm not wrong the command should be {0x80, 0x58, 0x5a, 0x132} but the last value exceed the char dimension... Should we just use 0x32 instead?
Thank you for your clarification.

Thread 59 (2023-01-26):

Arduino ide deepSleepInstant error

maxcalavera81, 2023-01-26:
Hello, I'm having a "deepSleepInstant" error and I don't know how to solve it. Does anyone have any idea how or what I'm doing wrong?

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

philibertc, 2023-01-26:
Hello, it seems that you have selected the esp32 version of the D1 mini, this program is made especially for the esp8266 version

maxcalavera81, 2023-01-27:
@philibertc thank you very much, problem solved. It really was the poorly selected board. Thanks a lot for the project.

philibertc, 2023-01-27:
Hello, I am glad to hear that. Could you please tell me the model of your stove if everything works well? You can make a pull request for this, and be listed among the contributors.

maxcalavera81, 2023-01-27:
My stuva is a cadel crystal .  I'll do some more testing and then I'll give you feedback.

Closed 2023-01-27.

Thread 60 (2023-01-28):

States missing micro nova n100

maxcalavera81, 2023-01-28:
Hello @philibertc , I was here doing some tests and I noticed that there are missing states or possibly different states in your firmware. In the case I had a failure in the ignition and it continues to report loading pellets. Can you give me tips on how to solve this problem? My salamander is a crystal cadel with n100 board.

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

The machine shows a failure to ignition, alarm 5

Thank you very much for your attention

philibertc, 2023-02-10:
Hello,
everything is working properly finally ?

Bests,
philibertc

maxcalavera81, 2023-02-10:
Hello @philibertc Thank you for your concern.  Yes, it's already working.  The problem was really with wemos.  There are small updates here that maybe could improve the experience with the salamander via Wi-Fi (I don't know if it will be possible or even easy to implement 😜😜).  One of them would be the online and offline status in mqtt because even if it is not online it always shows the online status.  The other thing I noticed these days is that when an alarm occurs, it is not possible to turn it off remotely because the switch immediately goes off.  Again, I don't know if such a change will be possible.  Smoke temperature is not displayed with real values   (I don't know if it only happens to me).  And as for the warnings, I had a lack of pellets in the stove when in reality it was a misfire.  I don't know what the behavior is in this case, but the stove's LCD shows the right alert.  These are small adjustments that could be improved over time.  I can't stop thanking you for the fantastic work you've done.  It was just what I needed to control my heat.  PS: if you add a web interface for those who don't have a home assistant, I think it would be really great...

Closed 2023-01-29.

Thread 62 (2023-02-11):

How to make it work with Alexa

jayjay13011, 2023-02-11:
Hello philibert.
All works so fine with my Extraflame Luisella. Thanks to you. But how I could make it works with Alexa. I try with fauxmo code but I’m a novice with all of this.
Could you help me?

Thanks by advance!

philibertc, 2023-02-11:
Hello,
unfortunately I don't know very well how to integrate devices in Alexa. I will look at fauxmoESP to see how it works.
What home automation platform are you currently using?

Best Regards,
Philibert

PS: I leave this issue open, as a feature request or suggestion.

jayjay13011, 2023-02-11:
I’m using Home Assistant.

I tried to integrate fauxmo, but my code is not correct and all the exemples I find on forums are for relays or lights. So it’s difficult for me to adapt it.

And for information, do you know why I have to restart my D1 MINI regularly since I flash your code.
￼

As you can see, I switched off near 12:30 but I don’t have datas since 11:45 and unfortunately, datas stay as they were when the D1 mini stopped.

Thanks.

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

jayjay13011, 2023-02-20:
@silkyclouds Thanks for the tip. I tried but I have a problem with https and duckdns: I can't access locally to HA when I activate https. I'll try again this week-end.
@philibertc My problem in #3 is always there. In fact, I think the ESP8266 goes in deep sleep mode and never wakes up. I connected D0 and RST. Do you know what can be the problem? Except this, all is ok, but I no longer can use it due to this problem because I can't switch on it after one hour or two running.

Thanks.

philibertc, 2023-02-20:
Hello, you can try to comment or delete lines 525 to 529 (from if to })

jayjay13011, 2023-02-21:
@philibertc  I did it, but same result... :-(

philibertc, 2023-02-21:
Argh, can you see what's going on with a serial monitor at that moment?

jayjay13011, 2023-02-26:
Here is the result after freeze with Exception Decoder :

`Exception 0: Illegal instruction
PC: 0x4021a750
EXCVADDR: 0x00000000

Decoding stack results
0x401011c6: check_poison_block(umm_block*) at C:\Users\Jeremy\AppData\Local\Arduino15\packages\esp8266\hardware\esp8266\3.1.1\cores\esp8266\umm_malloc/umm_poison.c line 86
0x40100c60: interrupt_handler(void*, void*) at C:\Users\Jeremy\AppData\Local\Arduino15\packages\esp8266\hardware\esp8266\3.1.1\cores\esp8266\core_esp8266_wiring_digital.cpp line 167
0x4010122c: check_poison_neighbors(umm_heap_context_t*, uint16_t) at C:\Users\Jeremy\AppData\Local\Arduino15\packages\esp8266\hardware\esp8266\3.1.1\cores\esp8266\umm_malloc/umm_local.c line 59
0x40100b9c: interrupt_handler(void*, void*) at C:\Users\Jeremy\AppData\Local\Arduino15\packages\esp8266\hardware\esp8266\3.1.1\cores\esp8266\core_esp8266_wiring_digital.cpp line 138
0x40224b24: mem_free at core/mem.c line 236
0x40100c60: interrupt_handler(void*, void*) at C:\Users\Jeremy\AppData\Local\Arduino15\packages\esp8266\hardware\esp8266\3.1.1\cores\esp8266\core_esp8266_wiring_digital.cpp line 167
0x4010091c: ets_post(uint8, ETSSignal, ETSParam) at C:\Users\Jeremy\AppData\Local\Arduino15\packages\esp8266\hardware\esp8266\3.1.1\cores\esp8266\core_esp8266_main.cpp line 238
0x40100b9c: interrupt_handler(void*, void*) at C:\Users\Jeremy\AppData\Local\Arduino15\packages\esp8266\hardware\esp8266\3.1.1\cores\esp8266\core_esp8266_wiring_digital.cpp line 138
0x4010091c: ets_post(uint8, ETSSignal, ETSParam) at C:\Users\Jeremy\AppData\Local\Arduino15\packages\esp8266\hardware\esp8266\3.1.1\cores\esp8266\core_esp8266_main.cpp line 238
0x40216be6: loop_task(ETSEvent*) at C:\Users\Jeremy\AppData\Local\Arduino15\packages\esp8266\hardware\esp8266\3.1.1\cores\esp8266\core_esp8266_main.cpp line 273
0x401000ab: app_entry_redefinable() at C:\Users\Jeremy\AppData\Local\Arduino15\packages\esp8266\hardware\esp8266\3.1.1\cores\esp8266\core_esp8266_main.cpp line 386
0x401011c6: check_poison_block(umm_block*) at C:\Users\Jeremy\AppData\Local\Arduino15\packages\esp8266\hardware\esp8266\3.1.1\cores\esp8266\umm_malloc/umm_poison.c line 86
0x401011c6: check_poison_block(umm_block*) at C:\Users\Jeremy\AppData\Local\Arduino15\packages\esp8266\hardware\esp8266\3.1.1\cores\esp8266\umm_malloc/umm_poison.c line 86
0x40101420: umm_malloc_core(umm_heap_context_t*, size_t) at C:\Users\Jeremy\AppData\Local\Arduino15\packages\esp8266\hardware\esp8266\3.1.1\cores\esp8266\umm_malloc/umm_local.c line 47
0x401010f8: get_poisoned(void*, size_t) at C:\Users\Jeremy\AppData\Local\Arduino15\packages\esp8266\hardware\esp8266\3.1.1\cores\esp8266\umm_malloc/umm_poison.c line 121
0x40211740: esp8266::MDNSImplementation::MDNSResponder::stcMDNSSendParameter::addDomainCacheItem(void const*, bool, unsigned short) at C:\Users\Jeremy\AppData\Local\Arduino15\packages\esp8266\hardware\esp8266\3.1.1\libraries\ESP8266mDNS\src\LEAmDNS_Structs.cpp line 2173
0x40101750: umm_malloc(size_t) at C:\Users\Jeremy\AppData\Local\Arduino15\packages\esp8266\hardware\esp8266\3.1.1\cores\esp8266\umm_malloc\umm_malloc.cpp line 912
0x40211740: esp8266::MDNSImplementation::MDNSResponder::stcMDNSSendParameter::addDomainCacheItem(void const*, bool, unsigned short) at C:\Users\Jeremy\AppData\Local\Arduino15\packages\esp8266\hardware\esp8266\3.1.1\libraries\ESP8266mDNS\src\LEAmDNS_Structs.cpp line 2173
0x401017c0: umm_poison_malloc(size_t) at C:\Users\Jeremy\AppData\Local\Arduino15\packages\esp8266\hardware\esp8266\3.1.1\cores\esp8266\umm_malloc/umm_poison.c line 169
0x40216a5b: operator new(unsigned int) at C:\Users\Jeremy\AppData\Local\Arduino15\packages\esp8266\hardware\esp8266\3.1.1\cores\esp8266\abi.cpp line 41
0x40212335: esp8266::MDNSImplementation::MDNSResponder::_udpAppendBuffer(unsigned char const*, unsigned int) at C:\Users\Jeremy\AppData\Local\Arduino15\packages\esp8266\hardware\esp8266\3.1.1\libraries\ESP8266mDNS\src\LEAmDNS_Transfer.cpp line 1163
0x4021263a: esp8266::MDNSImplementation::MDNSResponder::_writeMDNSRRDomain(esp8266::MDNSImplementation::MDNSResponder::stcMDNS_RRDomain const&, esp8266::MDNSImplementation::MDNSResponder::stcMDNSSendParameter&) at C:\Users\Jeremy\AppData\Local\Arduino15\packages\esp8266\hardware\esp8266\3.1.1\libraries\ESP8266mDNS\src\LEAmDNS_Transfer.cpp line 1395
0x402127f4: esp8266::MDNSImplementation::MDNSResponder::_writeMDNSServiceDomain(esp8266::MDNSImplementation::MDNSResponder::stcMDNSService const&, bool, bool, esp8266::MDNSImplementation::MDNSResponder::stcMDNSSendParameter&) at C:\Users\Jeremy\AppData\Local\Arduino15\packages\esp8266\hardware\esp8266\3.1.1\libraries\ESP8266mDNS\src\LEAmDNS_Transfer.cpp line 1502
0x4010091c: ets_post(uint8, ETSSignal, ETSParam) at C:\Users\Jeremy\AppData\Local\Arduino15\packages\esp8266\hardware\esp8266\3.1.1\cores\esp8266\core_esp8266_main.cpp line 238
0x4010091c: ets_post(uint8, ETSSignal, ETSParam) at C:\Users\Jeremy\AppData\Local\Arduino15\packages\esp8266\hardware\esp8266\3.1.1\cores\esp8266\core_esp8266_main.cpp line 238
0x4021d5d9: _printf_i at /workdir/repo/newlib/newlib/libc/stdio/nano-vfprintf_i.c line 174
0x40222354: _svfprintf_r at /workdir/repo/newlib/newlib/libc/stdio/nano-vfprintf.c line 662
0x40221f04: __ssputs_r at /workdir/repo/newlib/newlib/libc/stdio/nano-vfprintf.c line 232
0x40221f04: __ssputs_r at /workdir/repo/newlib/newlib/libc/stdio/nano-vfprintf.c line 232
0x40221f04: __ssputs_r at /workdir/repo/newlib/newlib/libc/stdio/nano-vfprintf.c line 232
0x40221e40: __ssputs_r at /workdir/repo/newlib/newlib/libc/stdio/nano-vfprintf.c line 182
0x4021d770: _printf_i at /workdir/repo/newlib/newlib/libc/stdio/nano-vfprintf_i.c line 246
0x40221f04: __ssputs_r at /workdir/repo/newlib/newlib/libc/stdio/nano-vfprintf.c line 232
0x4010091c: ets_post(uint8, ETSSignal, ETSParam) at C:\Users\Jeremy\AppData\Local\Arduino15\packages\esp8266\hardware\esp8266\3.1.1\cores\esp8266\core_esp8266_main.cpp line 238
0x40222101: _svfprintf_r at /workdir/repo/newlib/newlib/libc/stdio/nano-vfprintf.c line 528
0x4010091c: ets_post(uint8, ETSSignal, ETSParam) at C:\Users\Jeremy\AppData\Local\Arduino15\packages\esp8266\hardware\esp8266\3.1.1\cores\esp8266\core_esp8266_main.cpp line 238
0x401011c6: check_poison_block(umm_block*) at C:\Users\Jeremy\AppData\Local\Arduino15\packages\esp8266\hardware\esp8266\3.1.1\cores\esp8266\umm_malloc/umm_poison.c line 86
0x4010021f: SoftwareSerial::preciseDelay() at C:\Users\Jeremy\AppData\Local\Arduino15\packages\esp8266\hardware\esp8266\3.1.1\libraries\SoftwareSerial\src/SoftwareSerial.h line 246
0x4010021c: SoftwareSerial::preciseDelay() at C:\Users\Jeremy\AppData\Local\Arduino15\packages\esp8266\hardware\esp8266\3.1.1\libraries\SoftwareSerial\src/SoftwareSerial.h line 246
0x4021f395: _vsnprintf_r at /workdir/repo/newlib/newlib/libc/stdio/vsnprintf.c line 71
0x40216de1: esp_try_delay(unsigned int, unsigned int, unsigned int) at C:\Users\Jeremy\AppData\Local\Arduino15\packages\esp8266\hardware\esp8266\3.1.1\cores\esp8266\core_esp8266_main.cpp line 169
0x4021768c: __delay(unsigned long) at C:\Users\Jeremy\AppData\Local\Arduino15\packages\esp8266\hardware\esp8266\3.1.1\cores\esp8266/coredecls.h line 69
0x40201e88: SoftwareSerial::lazyDelay() at C:\Users\Jeremy\AppData\Local\Arduino15\packages\esp8266\hardware\esp8266\3.1.1\libraries\SoftwareSerial\src\SoftwareSerial.cpp line 345
0x40216c54: __esp_suspend() at C:\Users\Jeremy\AppData\Local\Arduino15\packages\esp8266\hardware\esp8266\3.1.1\cores\esp8266/core_esp8266_features.h line 64
0x40216da5: __esp_delay(unsigned long) at C:\Users\Jeremy\AppData\Local\Arduino15\packages\esp8266\hardware\esp8266\3.1.1\cores\esp8266\core_esp8266_main.cpp line 161
0x40216e1a: esp_try_delay(unsigned int, unsigned int, unsigned int) at C:\Users\Jeremy\AppData\Local\Arduino15\packages\esp8266\hardware\esp8266\3.1.1\cores\esp8266\core_esp8266_main.cpp line 182
0x4021768c: __delay(unsigned long) at C:\Users\Jeremy\AppData\Local\Arduino15\packages\esp8266\hardware\esp8266\3.1.1\cores\esp8266/coredecls.h line 69
0x40201878: getAmbTemp() at C:\Users\Jeremy\Documents\Arduino\PHILIBERT_ORIGINAL_MQTT_OK/PHILIBERT_ORIGINAL_MQTT_OK.ino line 400
0x402018d9: getStates() at C:\Users\Jeremy\Documents\Arduino\PHILIBERT_ORIGINAL_MQTT_OK/PHILIBERT_ORIGINAL_MQTT_OK.ino line 474
0x40201962: loop() at C:\Users\Jeremy\Documents\Arduino\PHILIBERT_ORIGINAL_MQTT_OK/PHILIBERT_ORIGINAL_MQTT_OK.ino line 523
`

After this, I have 2 other exception error. If you want, I can post them or send it to you in private.

Good week-end!

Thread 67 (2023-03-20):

Help installation

DEDEit, 2023-03-20:
Hi everyone!
Sorry but I just can't figure out how and which firmware I have to load on the ESP board, I have a weemos d1 mini and I've always configured everything with ESP HOME from the Home assistant.
Can you kindly give me a hand?
Of course I already have an mqtt server up and running.
I tried using the Arduino IDE but having never used it, I really have no idea how to do it.
A thousand thanks.

DEDEit, 2023-03-21:
closed

Closed 2023-03-21.

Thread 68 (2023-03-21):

Only on status works

DEDEit, 2023-03-21:
Hello everyone, I managed to configure everything but unfortunately the only working command is the ignition.
The shutdown does not work and I do not receive data on temperatures, flames, etc.
How can I check?
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

Maxx2828, 2023-12-23:
Same for me. Any solutions?

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

goldrake1981, 2024-09-16:
The same for me. Only state (late) and room temperature works. I stay nothing works. I have an extraflame viviana and should have micronova m011_1

Bougnat63, 2024-11-24:
Hello, were you able to find a solution? I have the same card and I'm looking to make this little module

goldrake1981, 2024-11-24:
nothing. I'm sorry.

maxapple71, 2024-12-07:
I have the same card on a MCZ polar and I had the same problem, but I SOLVED!! I debugged the levels and found that the RX_PIN D3 pin of the D1 Mini never went down, not even grounding the pin and therefore could not receive anything from the control unit. I modified the circuit board using the D1 pin instead of D3 with a 10k pull up resistance and of course I assigned RX_PIN to D1 in the code and now it works! I hope it's the solution for you too, but check it out quickly

dackerman38, 2025-01-29:
@maxapple71  Hi, Can you share a picture or diagram ? Thanks

grutttepier, 2025-09-17:
Here @Zenomathics84 made a diagram for it.
[https://github.com/philibertc/micronova_controller/issues/31#issuecomment-2710487294](url)

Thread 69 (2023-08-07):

unable to read values from the stove

hansf71, 2023-08-07:
Hello @philibertc , a short while ago I received your pcb. Installing the Wemos and the firmware was no problem, so far so good. Only I have a problem getting values from the stove. I've tried the test scripts and I am able to turn the stove ON and OFF with the onoff test script, but when trying to read one value or all values I never get any response. I added some extra serial output to verify the script is running, it is. But not one value is received.

Your pcb is connected to the Micronova pcb and powered over usb from my laptop. The 3.3v power connection is not used. In the photo you can see the setup I am testing with. The stove is a Tim Sistem Aquas 15.

Do you have any suggestions what to do next to solve this problem? I am able to do any test you suggest. Do I need to check my pcb for a problem?

Hope to hear from you. Thanks!
Hans

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

esavalle, 2024-01-07:
Hello @hansf71,
Did you manage to solve your problem ? I managed to get my stove info using [eni23's repository](https://github.com/eni23/micronova-controller) but I would like to get the MQTT integration that is only present in philibertc's repo.

I know that the communication with the stove is working thanks to eni23's work but I can get any answer from philibert's repo. So if you have managed to solve it, it would help me a lot !

hansf71, 2024-01-07:
Hi @esavalle,
I was not able to fix the problem yet. Due to lack of new input. But I still want to have a mqtt connection to my stove. Were you able to turn the stove on or off with philibertc's repo? I have an ESP32 somewhere and I will try to get eni32 repo working. From there I would think it would be possible to add mqtt support.
I will let you know. If you have any input or advise to get eni32 repo working, I'm all  ears!
Greetz
Hans

esavalle, 2024-01-08:
I indeed was already able to turn on and off the stove with philibertc's repo but as it was not working for the other command, I discovered eni23's repo which allow me to "decode" the communication.
eni23 was able to guide me a lot on how to make it work after a [few back and forth with him](https://github.com/eni23/micronova-controller/issues/8). Unfortunately, there is no MQTT integration yet but this is nothing too complicated I guess. I'll try to merge the two into something that will be functional for me and hopefully for someone else.

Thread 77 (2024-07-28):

activate "tempset"

c4coer, 2024-07-28:
bonjour j'ai besoin d'un peu d'aide donc j'ai utilisé le fichier de philibert, et j'ai voulu activer le reglage de temperature, donc j'ai activé toutes les parties "tempset", mais cela ne remonte pas dans le broker, c'est peut etre du a la ligne 57 ?

hello I need a little help so I used the philibert file, and I wanted to activate the temperature setting, so I activated all the "tempset" parts, but it does not go back to the broker, it may be due to the line 57 ?

"uint8_t stoveState, /tempSet,/fumesTemp, flamePower, waterTemp, tempSet /, waterSet/;"

thansks

c4coer, 2024-11-21:
> I have the same problem, I activated all the settings, there were more blocks. But no input is created in Homassistant. The function would be wonderful! I would be happy if there was more information on how to integrate and use this function.
>
> Thanks!

bonjour,
chez moi tout apparaît depuis

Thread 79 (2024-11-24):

Extraflame Melinda Idro serial problem?

Lumyn-IT, 2024-11-24:
Good evening to all.
I've connected mi stove with esp (other tests with rs232, also).
I've see correct query from esp to stove.
By stove, no any answer.

Is possible incorrect ram address?

Have you suggestion for solve my problem?
Thanks in advance.
Lele

dackerman38, 2025-01-29:
Hi,
I've had the same issue. There is an incompatibiliy between Philibert's pcb and some of micronova boards.

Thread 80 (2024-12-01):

Compatibilité poele MCZ flat confort air

herve8940, 2024-12-01:
Bonjour à tous,

Pourriez-vous me dire si mon poele mcz flat confort air est compatible avec le projet? Voici la reference de ma carte mère:41450907601.
D avance merci pour votre aide.

Hervé

philibertc, 2024-12-01:
Bonsoir,

Pouvez-vous m'indiquez si vous avez accès à un port série similaire à celui-ci (en dessous de Schematics) ? https://github.com/philibertc/micronova_controller/wiki/How-to-build-it#stoves-mainboard-pinout
Je ne parviens pas à voir s'il y en a un sur les photos disponibles sur Internet.

Merci

herve8940, 2024-12-01:
Bonsoir,

Voici la photo de ma carte mere:
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
Merci beaucoup pour votre aide.
Hervé

philibertc, 2024-12-01:
Malheureusement il ne semble pas y avoir le port nécessaire sur cette carte 😐

herve8940, 2024-12-01:
Mince! Je suis déçu 😞 voici le schéma électrique de la carte mere:
![Uploading 20241201_220153.jpg…]()

philibertc, 2024-12-01:
Désolé... Moi aussi, c'est la première fois que je tombe sur une carte mère sans port Série, je vais ajouter cette référence à la documentation pour plus tard
Le schéma électrique ne semble pas avoir été uploadé, c'est vrai que ça peut être intéressant d'y jeter un coup d'œil pour confirmer

herve8940, 2024-12-01:
Je suis quand meme étonné car je me dis qu il dois avoir une solution pour le dépannage. Il y a des connecteurs disponibles.
Voici le schéma:
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

herve8940, 2024-12-02:
Si ce n'est pas faisable avec votre projet, auriez-vous une autre méthode à me proposer ?
merci pour votre aide.
Hervé

philibertc, 2024-12-02:
Bonjour,

Effectivement le schéma confirme qu'il n'y a pas le port nécessaire malheureusement.
Comme autres solutions je vois seulement rajouter un transistor sur le bouton de l'écran pour simuler un appui (mais aucun retour avec cette solution) ou alors essayer de comprendre comment le module boutons/écran communique avec la carte mère (ce qui est beaucoup plus délicat)

Philibert

PS: au vu de cette discussion, faut-il que je maintienne la commande sur Tindie ?

philibertc, 2024-12-07:
Bonjour,
C'est une télécommande IR ? Si oui, il est alors éventuellement possible de capturer les signaux transmis pour les simuler ensuite avec un arduino ou équivalent.

Closed 2024-12-07.

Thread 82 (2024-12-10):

the stove does not turn on

maxapple71, 2024-12-10:
By sending the ignition command the stove turns on and loads pellets but it does not turn on and then there is an error. The glow plug is cold...If I turn on the stove from its display everything works correctly. It's a MCZ Polar hydro, communication with the stove works and the on/off test works correctly, can read all data...how can I do it?

maxapple71, 2024-12-11:
I paid attention and if I turn on the stove with the button I hear the tick of a relay (which powers the glow plug), while I don't hear it when I send the command {0x80, 0x21, 0x01, 0xA2}...
[just turned on with the power button.log](https://github.com/user-attachments/files/18097323/just.turned.on.with.the.power.button.log)
[OFF.log](https://github.com/user-attachments/files/18097324/OFF.log)

maxapple71, 2024-12-14:
Thanks to fabrizioromanelli I was able to turn on the stove properly! With this {0x80, 0x58, 0x5A, 0x132} my Mcz started!

c4coer, 2025-05-08:
bonjour comment avez vous trouvé ce code ?

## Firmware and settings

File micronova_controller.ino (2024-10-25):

#define mqtt_server "192.168.X.X"
#define mqtt_port 1883
#define mqtt_topic "micronova"
#define mqtt_user "usrname"
#define mqtt_pass "passwd"
#define hydro_mode 0

#include <SoftwareSerial.h>
SoftwareSerial StoveSerial;
#define SERIAL_MODE SWSERIAL_8N2 //8 data bits, parity none, 2 stop bits
#define RESET_PIN D5
#define RX_PIN D3
#define TX_PIN D4
#define ENABLE_RX D2

#include <ArduinoOTA.h>
#include <WiFiManager.h>
#include <PubSubClient.h>

WiFiClient espClient;
PubSubClient client(espClient);
WiFiManager wm;

int deepSleep = 0;
long previousMillis;

#define pong_topic mqtt_topic "/pong"
#define state_topic mqtt_topic "/state"
#define tempset_topic mqtt_topic "/tempset"
#define onoff_topic mqtt_topic "/onoff"
#define ambtemp_topic mqtt_topic "/ambtemp"
#define fumetemp_topic mqtt_topic "/fumetemp"
#define flame_topic mqtt_topic "/flamepower"
#define watertemp_topic mqtt_topic "/watertemp"
//#define waterset_topic mqtt_topic "/waterset"
#define waterpres_topic mqtt_topic "/waterpres"
#define pwrget_topic mqtt_topic "/stovepower"
#define in_topic mqtt_topic "/intopic"

#define device_information "{\"manufacturer\": \"Philibert Cheminot\",\"identifiers\": [\"7a396f39-80d2-493b-8e8e-31a70e700bc6\"],\"model\": \"Micronova Controller\",\"name\": \"Micronova Controller\",\"sw_version\": \"1.0.0.0\"}"

//0 - OFF, 1 - Starting, 2 - Pellet loading, 3 - Ignition, 4 - Work, 5 - Brazier cleaning, 6 - Final cleaning, 7 - Standby, 8 - Pellet missing alarm, 9 - Ignition failure alarm, 10 - Alarms (to be investigated)

//Checksum: Code+Address+Value on hexadecimal calculator

const char stoveOn[4] = {0x80, 0x21, 0x01, 0xA2};
const char stoveOff[4] = {0x80, 0x21, 0x06, 0xA7};
const char forceOff[4] = {0x80, 0x21, 0x00, 0xA1};

#define stoveStateAddr 0x21
#define ambTempAddr 0x01
#define ambTempAddr 0x01
#define tempSetAddr 0x7D
#define tempGetAddr 0x9D
#define pwrSetAddr 0x7F
#define pwrGetAddr 0x9F
#define fumesTempAddr 0x3E
#define flamePowerAddr 0x34
#define waterTempAddr 0x03
//#define waterSetAddr 0x36
#define waterPresAddr 0x3C

uint8_t stoveState, tempSet, pwrSet, fumesTemp, flamePower, waterTemp /*, waterSet*/;
float ambTemp, waterPres;
char stoveRxData[2]; //When the heater is sending data, it sends two bytes: a checksum and the value
int chksum, intfromtemp;
byte hexdumpo, checksum;
String rcvTemp;
String rcvData;

void setup_wifi() //Setup WiFiManager and connect to WiFi
{
    ArduinoOTA.setHostname(mqtt_topic);
    ArduinoOTA.setPassword("micronova");
    ArduinoOTA.begin();
    WiFi.mode(WIFI_STA);
    wm.setConnectTimeout(30);
    wm.autoConnect(mqtt_topic);
}

void reconnect() //Connect to MQTT server
{
    //Loop until we're reconnected
    while (!client.connected())
    {
        Serial.println(mqtt_user);
        Serial.println(mqtt_pass);
        Serial.print("Attempting MQTT connection...");
        String clientId = "ESPClient-";
        clientId += String(random(0xffff), HEX); //Random client ID
        if (client.connect(clientId.c_str(), mqtt_user, mqtt_pass))
        {
            client.setBufferSize(1024);
            Serial.println("connected");
        }
        else
        {
            Serial.print("failed, rc=");
            Serial.print(client.state());
            Serial.println(" try again in 5 seconds");
            //Wait 5 seconds before retrying
            delay(5000);
        }
    }
    if (client.connected())
    {
      Serial.println("Creating topics for HomeAssistant");

      String switch_topic = "homeassistant/switch/Micronova/Controller/config";
      String switch_payload = "{\"name\": \"Controller\", \"command_topic\": \"" in_topic "\", \"state_topic\": \"" onoff_topic "\", \"payload_on\": \"ON\", \"payload_off\": \"OFF\", \"state_on\": \"ON\", \"state_off\": \"OFF\", \"retain\":false, \"optimistic\": false, \"qos\": 0, \"icon\": \"mdi:fire\", \"unique_id\": \"d5668e9c-843c-4330-ae53-a5bd135a4412\", \"device\": " device_information "}";
      client.publish(switch_topic.c_str(), switch_payload.c_str(), true);

      String sensor_topic = "homeassistant/sensor/Micronova/Controller/config";
      String sensor_payload = "{\"name\": \"Controller\", \"state_topic\": \"" pong_topic "\", \"qos\": 0, \"icon\": \"mdi:power\", \"unique_id\": \"0038ec49-3921-4f1b-9fa9-71acb04052fa\",\"device\": " device_information "}";
      client.publish(sensor_topic.c_str(), sensor_payload.c_str(), true);

      String temperature_sensor_topic = "homeassistant/sensor/Micronova/Temperature/config";
      String temperature_sensor_payload = "{\"name\": \"Temperature\", \"state_topic\": \"" ambtemp_topic "\", \"qos\": 0, \"device_class\": \"temperature\", \"state_class\": \"measurement\", \"unit_of_measurement\": \"°C\", \"icon\": \"mdi:thermometer\", \"unique_id\": \"9db3245e-6ace-4d14-ac07-844cd68d245c\",\"device\": " device_information "}";
      client.publish(temperature_sensor_topic.c_str(), temperature_sensor_payload.c_str(), true);

      String fumes_temperature_sensor_topic = "homeassistant/sensor/Micronova/FumesTemperature/config";
      String fumes_temperature_sensor_payload = "{\"name\": \"Fumes Temperature\", \"state_topic\": \"" fumetemp_topic "\", \"qos\": 0, \"device_class\": \"temperature\", \"state_class\": \"measurement\", \"unit_of_measurement\": \"°C\", \"icon\": \"mdi:thermometer\", \"unique_id\": \"3c72e1cf-bc22-499e-9f85-7c7e960f9a95\",\"device\": " device_information "}";
      client.publish(fumes_temperature_sensor_topic.c_str(), fumes_temperature_sensor_payload.c_str(), true);

      String state_sensor_topic = "homeassistant/sensor/Micronova/State/config";
      String state_sensor_payload = "{\"name\": \"State\", \"state_topic\": \"" state_topic "\", \"qos\": 0, \"icon\": \"mdi:fire-alert\", \"unique_id\": \"62fe5080-7668-409b-8451-323364b42eff\",\"device\": " device_information "}";
      client.publish(state_sensor_topic.c_str(), state_sensor_payload.c_str(), true);

      String flame_power_sensor_topic = "homeassistant/sensor/Micronova/FlamePower/config";
      String flame_power_sensor_payload = "{\"name\": \"Flame Power\", \"state_topic\": \"" flame_topic "\", \"qos\": 0, \"unit_of_measurement\": \"%\", \"icon\": \"mdi:fire\", \"unique_id\": \"c3aecb86-66e2-4358-bccb-e3b620f3d28b\",\"device\": " device_information "}";
      client.publish(flame_power_sensor_topic.c_str(), flame_power_sensor_payload.c_str(), true);

      if (hydro_mode == 1)
      {
        String water_temperature_sensor_topic = "homeassistant/sensor/Micronova/WaterTemperature/config";
        String water_temperature_sensor_payload = "{\"name\": \"Water Temperature\", \"state_topic\": \"" watertemp_topic "\", \"qos\": 0, \"device_class\": \"temperature\", \"state_class\": \"measurement\", \"unit_of_measurement\": \"°C\", \"icon\": \"mdi:coolant-temperature\", \"unique_id\": \"7eb9a6b2-8e26-49f0-b75a-dd97f537d856\",\"device\": " device_information "}";
        client.publish(water_temperature_sensor_topic.c_str(), water_temperature_sensor_payload.c_str(), true);

        String water_pressure_sensor_topic = "homeassistant/sensor/Micronova/WaterPressure/config";
        String water_pressure_sensor_payload = "{\"name\": \"Water Pressure\", \"state_topic\": \"" waterpres_topic "\", \"qos\": 0, \"device_class\": \"pressure\", \"unit_of_measurement\": \"bar\", \"icon\": \"mdi:gauge\", \"unique_id\": \"2e272bb3-7b55-4867-bf1a-b8772d0ae90d\", \"device\": " device_information "}";
        client.publish(water_pressure_sensor_topic.c_str(), water_pressure_sensor_payload.c_str(), true);
      }

      Serial.println("HomeAssistant topics created.");
    }
}

void IRAM_ATTR fullReset() //Reset all the settings but without erasing the program
{
    Serial.println("Resetting…");
    wm.resetSettings();
    ESP.restart();
}

void callback(char *topic, byte *payload, unsigned int length)
{
    Serial.print("Message arrived [");
    Serial.print(topic);
    Serial.print("] ");
 
    for (int i = 0; i < length; i++)
    {
        Serial.print((char)payload[i]);
    }
    Serial.println();
    if ((char)payload[1] == 'N')
    {
        for (int i = 0; i < 4; i++)
        {
            if (stoveState > 5)
            {
                StoveSerial.write(stoveOn[i]);
                delay(1);
            }
            else if (stoveState == 0)
            {
                StoveSerial.write(stoveOn[i]);
                delay(1);
            }
        }
        client.publish(onoff_topic, "ON", true);
        delay(1000);
        getStates();
    }
    else if ((char)payload[1] == 'F')
    {
        for (int i = 0; i < 4; i++)
        {
            if (stoveState < 6)
            {
                if (stoveState > 0)
                {
                    StoveSerial.write(stoveOff[i]);
                    delay(1);
                }
            }
        }
        client.publish(onoff_topic, "OFF", true);
        delay(1000);
        getStates();
    }
    else if ((char)payload[0] == '0')
    {
        for (int i = 0; i < 4; i++)
        {
            if (stoveState < 6)
            {
                if (stoveState > 0)
                {
                    StoveSerial.write(stoveOff[i]);
                    delay(1);
                }
            }
        }
        client.publish(onoff_topic, "OFF", true);
        delay(1000);
        getStates();
    }
    else if ((char)payload[0] == '1')
    {
        for (int i = 0; i < 4; i++)
        {
            if (stoveState > 5)
            {
                StoveSerial.write(stoveOn[i]);
                delay(1);
            }
            else if (stoveState == 0)
            {
                StoveSerial.write(stoveOn[i]);
                delay(1);
            }
            client.publish(onoff_topic, "ON", true);
            delay(1000);
            getStates();
        }
    }
    else if ((char)payload[0] == 'f')
    {
        if ((char)payload[1] == 'o')
        {
            for (int i = 0; i < 4; i++)
            {
                StoveSerial.write(forceOff[i]);
                delay(1);
            }
            client.publish(onoff_topic, "OFF", true);
            delay(1000);
            getStates();
        }
    }
    else if ((char)payload[0] == 'S')
    {
        deepSleep = 1;
    }
    else if ((char)payload[0] == 'W')
    {
        deepSleep = 0;
    }
    else if ((char)payload[2] == 's')
    {
        fullReset();
    }
      else if ((char)payload[0] == 'T')
    {
      rcvData="";
       for (int i = 1; i < length; i++)
      {
        rcvData+=(char)payload[i];
        
      }
     intfromtemp = rcvData.toInt()*2;
     hexdumpo=(byte)intfromtemp;
     chksum = (0xA0+0x7d+hexdumpo)-256;
     StoveSerial.write((byte)0xA0);
     delay(1);
     StoveSerial.write((byte)0x7D);
     delay(1);
     StoveSerial.write((byte)intfromtemp);
     delay(1);
     StoveSerial.write((byte)chksum);
     delay(120);
     getStates();
  }
     else if ((char)payload[0] == 'P')
    {
      rcvData="";
       for (int i = 1; i < length; i++)
      {
        rcvData+=(char)payload[i];
        
      }
      intfromtemp = rcvData.toInt();
      hexdumpo=(byte)intfromtemp;
      chksum = (0xA0+0x7F+hexdumpo)-256;
      StoveSerial.write((byte)0xA0);
     delay(1);
     StoveSerial.write((byte)0x7F);
     delay(1);
     StoveSerial.write((byte)intfromtemp);
     delay(1);
     StoveSerial.write((byte)chksum);
     delay(120);
     getStates();
     
     
   }
}

void checkStoveReply() //Works only when request is RAM
{
    uint8_t rxCount = 0;
    stoveRxData[0] = 0x00;
    stoveRxData[1] = 0x00;
    while (StoveSerial.available()) //It has to be exactly 2 bytes, otherwise it's an error
    {
        stoveRxData[rxCount] = StoveSerial.read();
        rxCount++;
    }
    digitalWrite(ENABLE_RX, HIGH);
    if (rxCount == 2)
    {
        byte val = stoveRxData[1];
        byte checksum = stoveRxData[0];
        byte param = checksum - val;
        Serial.printf("Param=%01x value=%01x ", param, val);
        switch (param)
        {
        case stoveStateAddr:
            stoveState = val;
            switch (stoveState)
            {
            case 0:
                client.publish(state_topic, "Off", true);
                delay(1000);
                client.publish(onoff_topic, "OFF", true);
                break;
            case 1:
                client.publish(state_topic, "Starting", true);
                delay(1000);
                client.publish(onoff_topic, "ON", true);
                break;
            case 2:
                client.publish(state_topic, "Pellet loading", true);
                delay(1000);
                client.publish(onoff_topic, "ON", true);
                break;
            case 3:
                client.publish(state_topic, "Ignition", true);
                delay(1000);
                client.publish(onoff_topic, "ON", true);
                break;
            case 4:
                client.publish(state_topic, "Working", true);
                delay(1000);
                client.publish(onoff_topic, "ON", true);
                break;
            case 5:
                client.publish(state_topic, "Brazier cleaning", true);
                break;
            case 6:
                client.publish(state_topic, "Final cleaning", true);
                delay(1000);
                client.publish(onoff_topic, "OFF", true);
                break;
            case 7:
                client.publish(state_topic, "Standby", true);
                delay(1000);
                client.publish(onoff_topic, "OFF", true);
                break;
            case 8:
                client.publish(state_topic, "Pellet missing", true);
                break;
            case 9:
                client.publish(state_topic, "Ignition failure", true);
                delay(1000);
                client.publish(onoff_topic, "OFF", true);
                break;
            case 10:
                client.publish(state_topic, "Alarm", true);
                break;
            }
            Serial.printf("Stove %s\n", stoveState ? "ON" : "OFF");
            break;
        case ambTempAddr:
            ambTemp = (float)val / 2;
            client.publish(ambtemp_topic, String(ambTemp).c_str(), true);
            Serial.print("T. amb. ");
            Serial.println(ambTemp);
            break;
         case tempGetAddr:
            tempSet = (float)val / 2;
            client.publish(tempset_topic, String(tempSet).c_str(), true);
            Serial.printf("T. set %d\r\n", tempSet);
            break;
        case pwrGetAddr:
            pwrSet = (float)val;
            client.publish(pwrget_topic, String(pwrSet).c_str(), true);
            Serial.printf("Pwr set %d\r\n", pwrSet);
            break;
        case fumesTempAddr:
            fumesTemp = val;
            client.publish(fumetemp_topic, String(fumesTemp).c_str(), true);
            Serial.printf("T. fumes %d\n", fumesTemp);
            break;
        case flamePowerAddr:
            if (stoveState < 6)
            {
                if (stoveState > 0)
                {
                    flamePower = map(val, 0, 16, 10, 100);
                }
            }
            else
            {
                flamePower = 0;
            }
            client.publish(flame_topic, String(flamePower).c_str(), true);
            Serial.printf("Fire %d\n", flamePower);
            break;
        case waterTempAddr:
            waterTemp = val;
            client.publish(watertemp_topic, String(waterTemp).c_str(), true);
            Serial.printf("T. water %d\n", waterTemp);
            break;
        /*case waterSetAddr:
            waterSet = val;
            client.publish(waterset_topic, String(waterSet).c_str(), true);
            Serial.printf("T. water set %d\n", waterSet);
            break;*/
        case waterPresAddr:
            waterPres = (float)val / 10;
            client.publish(waterpres_topic, String(waterPres).c_str(), true);
            Serial.print("Pressure ");
            Serial.println(waterPres);
            break;
        }
    }
}

void getStoveState() //Get detailed stove state
{
    const byte readByte = 0x00;
    StoveSerial.write(readByte);
    delay(1);
    StoveSerial.write(stoveStateAddr);
    digitalWrite(ENABLE_RX, LOW);
    delay(80);
    checkStoveReply();
}

void getAmbTemp() //Get room temperature
{
    const byte readByte = 0x00;
    StoveSerial.write(readByte);
    delay(1);
    StoveSerial.write(ambTempAddr);
    digitalWrite(ENABLE_RX, LOW);
    delay(80);
    checkStoveReply();
}

void getTempSet() //Get the thermostat setting
{
    const byte readByte = 0x20;
    StoveSerial.write(readByte);
    delay(1);
    StoveSerial.write(tempSetAddr);
    digitalWrite(ENABLE_RX, LOW);
    delay(60);
    checkStoveReply();
}
void getPwrSet() //Get the thermostat setting
{
    const byte readByte = 0x20;
    StoveSerial.write(readByte);
    delay(1);
    StoveSerial.write(pwrSetAddr);
    digitalWrite(ENABLE_RX, LOW);
    delay(80);
    checkStoveReply();
}
void getFumeTemp() //Get flue gas temperature
{
    const byte readByte = 0x00;
    StoveSerial.write(readByte);
    delay(1);
    StoveSerial.write(fumesTempAddr);
    digitalWrite(ENABLE_RX, LOW);
    delay(80);
    checkStoveReply();
}

void getFlamePower() //Get the flame power (0, 1, 2, 3, 4, 5)
{
    const byte readByte = 0x00;
    StoveSerial.write(readByte);
    delay(1);
    StoveSerial.write(flamePowerAddr);
    digitalWrite(ENABLE_RX, LOW);
    delay(80);
    checkStoveReply();
}

void getWaterTemp() //Get the temperature of the water (if you have an hydro heater)
{
    const byte readByte = 0x00;
    StoveSerial.write(readByte);
    delay(1);
    StoveSerial.write(waterTempAddr);
    digitalWrite(ENABLE_RX, LOW);
    delay(80);
    checkStoveReply();
}

/* void getWaterSet() //Get the temperature of the water (if you have an hydro heater)
{
    const byte readByte = 0x00;
    StoveSerial.write(readByte);
    delay(1);
    StoveSerial.write(waterSetAddr);
    digitalWrite(ENABLE_RX, LOW);
    delay(80);
    checkStoveReply();
}
*/

void getWaterPres() //Get the temperature of the water (if you have an hydro heater)
{
    const byte readByte = 0x00;
    StoveSerial.write(readByte);
    delay(1);
    StoveSerial.write(waterPresAddr);
    digitalWrite(ENABLE_RX, LOW);
    delay(80);
    checkStoveReply();
}

void getStates() //Calls all the get…() functions
{
    getStoveState();
    delay(100);
    getAmbTemp();
    delay(100);
    getTempSet();
    delay(100);
    getPwrSet();
    getFumeTemp();
    delay(100);
    getFlamePower();
    if (hydro_mode == 1)
    {
        delay(100);
        getWaterTemp();
        delay(100);
        /*getWaterSet();
        delay(100);*/
        getWaterPres();
    }
}

void setup()
{
    pinMode(ENABLE_RX, OUTPUT);
    digitalWrite(ENABLE_RX, HIGH); //The led of the optocoupler is off
    pinMode(RESET_PIN, INPUT_PULLUP);
    attachInterrupt(digitalPinToInterrupt(RESET_PIN), fullReset, FALLING); //We setup the reinit interrupt
    Serial.begin(115200);
    StoveSerial.begin(1200, SERIAL_MODE, RX_PIN, TX_PIN, false, 256);
    setup_wifi();
    client.setServer(mqtt_server, mqtt_port);
    client.setCallback(callback);
    client.subscribe(in_topic);
}

void loop()
{
    if (!client.connected())
    {
        reconnect();
        client.subscribe(in_topic);
    }
    client.loop();
    ArduinoOTA.handle();
    unsigned long currentMillis = millis();
    if (previousMillis > currentMillis)
    {
        previousMillis = 0;
    }
    if (currentMillis - previousMillis >= 25000)
    {
        previousMillis = currentMillis;
        getStates();
        client.publish(pong_topic, "Connected");
    }
    if (deepSleep == 1)   //Does not work without hardaware modification (a cable must be connected between RST and D0)
    {
        Serial.println("Deep Sleep");
        ESP.deepSleepInstant(300e6);
    }
}

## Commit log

2021-08-07 Correcting errors
    Tests are working.
    [test1_on_off.ino, test2_read.ino]
2021-08-14 Update PCB
    [PCB.kicad_pcb, PCB.sch]
2021-08-14 Better arrangement of the traces
    [PCB.kicad_pcb]
2021-08-14 500R to 510R
    [PCB.kicad_pcb]
2021-08-14 Add gerber files
    [PCB-B_Cu.gbr, PCB-B_Mask.gbr, PCB-B_Paste.gbr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]
2021-09-03 Non important PCB changes
    [PCB.kicad_pcb]
2021-09-03 Regenerating gerber
    [PCB-B_Cu.gbr, PCB-B_Mask.gbr, PCB-B_Paste.gbr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]
2021-09-05 Smaller PCB
    [PCB-B_Cu.gbr, PCB-B_Mask.gbr, PCB-B_Paste.gbr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]
2021-09-05 Flame power 0 = 0FF
2021-09-25 Removing buggy new features Will be reimplemented after debug.
    [micronova_controller.ino]
2021-09-25 New features and corrections
    [micronova_controller.ino]
2021-10-02 Water pressure in bar
2021-10-03 Pong "Powered up" is sent every 25s on mqtt_topic/pong
2021-10-03 Correcting errors in comments
    [micronova_controller.ino]
2021-10-18 PCB v2
    Soon on Tindie (if there are enough people interested)
    https://github.com/philibertc/micronova_controller/discussions/17#discussioncomment-1496990
    [PCB.kicad_pcb, PCB.sch]
2021-10-18 Update PCB's legends
    [PCB.kicad_pcb]
2021-10-20 Removal of obsolete Gerber files
    [PCB-B_Cu.gbr, PCB-B_Mask.gbr, PCB-B_Paste.gbr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]
2021-10-24 Final Gerber
    Files used for the "v2" version sold on Tindie.
    [PCB-B_Cu.gbl, PCB-B_Mask.gbs, PCB-B_Paste.gbp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]
2021-10-31 Create PCB.kicad_pcb-rounded
2021-11-07 Fixes in test prog
    [test2_read.ino]
2022-03-06 Correcting comments Please use commit 6b27eb0
    [micronova_controller.ino]
2022-03-06 Correcting duplicated reconnect() Please use commit 6b27eb0
    [micronova_controller.ino]
2022-09-03 CC-BY-NC-ND to CC-BY-NC-SA
    [PCB-B_Cu.gbl, PCB-B_Mask.gbs, PCB-B_Paste.gbp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]
2022-10-29 fix: variable waterset is wrong
    [micronova_controller.ino]
2022-10-31 feat: adds AutoDiscover sensors for HomeAssistant
2022-11-13 Update to read / write temps & stove power
    Dirty values code - but works like a charm on Feretti stove.
    For reading EEPROM values we must add 0x20 to the address - the stove replies with added value (e.g. 0x7F becomes 0x9F in RX from stove, we still write to 0x7F)
    TODO: calculate checksum automagically, if checskum is higher than 0xFF then we must substract 256Dec from value - now we MUST know if the value will be higher than 0xFF and calculate accordingly.
    Confirm working for ~7 days with HomeAssistant.
2022-12-30 Add new Model "L'Asolana Marina"
    Hey, as promised in #53, here my MR:
    This model has no boiler at all. I figured out a few more options to control, see here: https://github.com/eni23/micronova-controller#known-locations but the ones you use for temp, fumes, fan and tur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
2023-02-18 Update micronova_controller.ino
    Changed the º symbol, that is the masculine ordinal indicator to the correct ° degree symbol.
    [micronova_controller.ino]
2025-11-05 Enhance PCBWay info
    Updated PayPal donation link and improved PCBWay description.
